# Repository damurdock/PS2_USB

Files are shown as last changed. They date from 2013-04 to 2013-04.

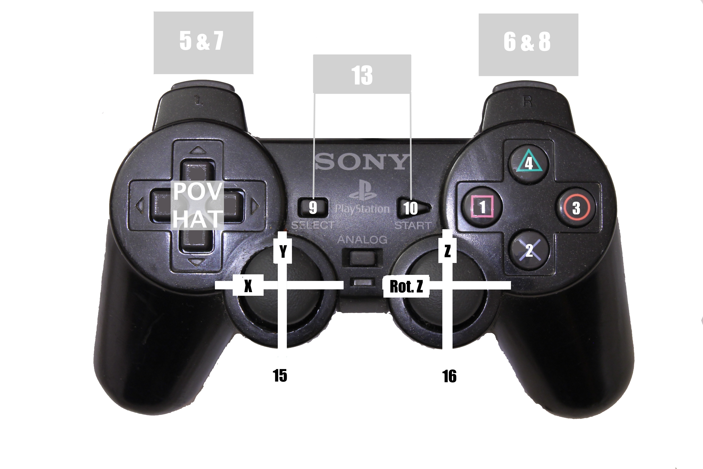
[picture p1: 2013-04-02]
Button Diagram.jpg

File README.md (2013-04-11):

##PS2-USB

###Requirements
To setup and use PS2-USB, you'll need:
  * A PJRC Teensy 2.0
  * A copy of Arduino 1.0 or higher with Teensyduino installed 
  * Either
    * Two (2) 5.6k resistors
    * Or to convert your Teensy to 3.3 volts
  * One (1) 10k resistor
  * Either some perfboard, or a PCB made from the provided files
  * Header pins or wire, depending on how you build PS2-USB
  * A PS2 Controller (non-3.3v version only tested with official Dualshock 2 controller)
  * A method of connecting your controller to the circuit
  
###Wiring
PS2-USB can be used in two configurations, 5v and 3.3v. CadSoft EAGLE board and schematics are available in the hardware directory. If you are using perfboard, a breadboard, a freehand circuit, or any other method, follow these instructions.

####5v
NOTE: The 5v version has only been tested and confirmed to work with an official Sony Dualshock 2 controller. Your results may vary.
Thanks to Bill Porter and Curious Inventor for their work, diagrams, and instructions.

Controller ---------------> Teensy  
Pin 1 ----------> Pin B3  
&nbsp;&nbsp;&nbsp;&nbsp;&nbsp;&nbsp;&nbsp;&nbsp;&nbsp;&nbsp;|-----(10k resistor)--> VCC  
Pin 2 ---------> Pin B1  
Pin 3 NC  
Pin 4 ---------> GND  
Pin 5 ---------> VCC  
Pin 6 --(5.6k resistor)--> Pin B2  
Pin 7 --(5.6k resistor)--> Pin B0  
Pin 8 NC  
Pin 9 NC  

####3.3v
NOTE: This requires that you [convert your Teensy to 3.3 volts](http://www.pjrc.com/teensy/3volt.html) or [run it from an external 3.3 volt supply] (http://www.pjrc.com/teensy/external_power.html).
Thanks to Bill Porter and Curious Inventor for their work, diagrams, and instructions.

Controller --------------> Teensy  
Pin 1 ----------> Pin B3  
&nbsp;&nbsp;&nbsp;&nbsp;&nbsp;&nbsp;&nbsp;&nbsp;&nbsp;&nbsp;|-----(10k resistor)--> VCC  
Pin 2 ---------> Pin B1  
Pin 3 NC    
Pin 4 ---------> GND  
Pin 5 ---------> VCC  
Pin 6 ---------> Pin B2  
Pin 7 ---------> Pin B0  
Pin 8 NC  
Pin 9 NC  

###Software
The PS2-USB software is written in Teensyduino, which means that you need to have a a current (1.0 or above) version of the Arduino software installed, as well as the PJRC Teensyduino software.

To setup the software, simply open PS2_USB.ino in Arduino, select "Teensy 2.0" as the board type, "Keyboard \+ Mouse \+ Joystick" as the USB type, and "16 MHz" as the CPU speed (8 MHz if running on 3.3 volts). Then, hit verify, and wait for the Teensy Loader to open. When Teensy Loader is open, make sure your Teensy is connected and hit the reset button on the Teensy. After the code is loaded, you're good to go!

###Playstation 3
PS2-USB is now fully compatible with the Playstation 3! All buttons and axes will work by default. In order to use the "PS button", install the Teensyduino PS Button Mod located [here](https://github.com/damurdock/Teensyduino-PS-Button-Mod). Pressing Start and Select at the same time sends the PS button.

###Usage
PS2-USB shouldn't require any extra work once the hardware is built and the software loaded. There are a few things you should know, however. When PS2-USB is connected, the Teensy's LED will indicate its' status. If the light is flashing, either no controller is connected, or PS2X cannot talk to the controller. Try the instructions on [this page](http://www.billporter.info/arduino-playstation-2-controller-library-troubleshooting-guide/), or try using the 3.3 volt version. Once your controller is working, you may want to look at the Button Diagram.jpg file to see how the buttons are numbered (This diagram is based on a diagram available on the PJRC website. Photo taken by Duncan Murdock, Playstation is a registered trademark of Sony).

###Credits
PS2-USB relies upon the [PS2X library by Bill Porter] (http://www.billporter.info/playstation-2-controller-arduino-library-v1-0/) and the [PJRC Teensyduino joystick library] (http://www.pjrc.com/teensy/td_joystick.html). I would also like to thank Curious Inventor for their PS2 controller interface guide, and Bill Porter for his troubleshooting guide. 

PS2-USB's hardware uses parts from the Sparkfun Eagle Library, as well a modified part for the Teensy 2.0 created by Mark Gross. The modified version, details, and license are in the hardware directory.

PS2-USB is written and maintained by Duncan Murdock. PS2-USB and all related works by Duncan Murdock are licensed under the MIT License unless otherwise noted. A copy of the MIT License is provided in the accompanying LICENSE file. If the LICENSE file is not included or is damaged in some way, a copy can be viewed at http://www.opensource.org/licenses/mit-license.php.

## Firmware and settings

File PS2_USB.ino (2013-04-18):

/******************************************************************************
 *                                 PS2-USB                                     *
 *=============================================================================*
 *                             By: Duncan Murdock                              *
 *                             Date: 1/20/2012                                 *
 *                             Version: 4                                      *
 *+++++++++++++++++++++++++++++++++++++++++++++++++++++++++++++++++++++++++++++*
 *  Uses a Teensy 2.0 in Joystick mode to convert a PS2 controller to USB.     *
 * Based on the PJRC Joystick example and Bill Porter's excellent PS2X library *
 * Hardware and software are currently TESTED. Licensed under the MIT license  *
 * , a copy of which is located in the included LICENSE file.                  *
 *                                 Enjoy!                                      *
 *-----------------------------------------------------------------------------*
 *                       https://github.com/damurdock                          *
 ******************************************************************************/

#include <PS2X_lib.h>
PS2X controller;
int error = 0;
byte type = 0;
boolean config = false;

void setup(){
  error = controller.config_gamepad(0,1,2,3, false, false); // setup controller, config_gamepad(clock, command, attention, data, Pressures?, Rumble?); rumble and pressures currently unsupported
    //Guitar Hero controllers should work now. I don't have one to test though.
}

void loop(){
  if(error == 1){ // flash led if there's an error
    digitalWrite(11,HIGH); 
    delay(500);
    digitalWrite(11,LOW); 
    delay(500);
    error = controller.config_gamepad(0,1,2,3, false, false); // Try to setup the controller again
  }
  else if (!config) { // turn on the LED and get controller type if all's well
    digitalWrite(11,HIGH); 
    type = controller.readType();
    config = true;
  }
  controller.read_gamepad(); //read the controller
  // testing out sending the usb packet spontaneously, should reduce lag a bit
  if(type !=2){ 
    Joystick.button(1, controller.Button(PSB_PINK));
    Joystick.button(2, controller.Button(PSB_BLUE));
    Joystick.button(3, controller.Button(PSB_RED));
    Joystick.button(4, controller.Button(PSB_GREEN));
    Joystick.button(5, controller.Button(PSB_L1));
    Joystick.button(6, controller.Button(PSB_R1));
    Joystick.button(7, controller.Button(PSB_L2));
    Joystick.button(8, controller.Button(PSB_R2));
    Joystick.button(11, controller.Button(PSB_L3));
    Joystick.button(12, controller.Button(PSB_R3));
    
    // working on PS3 compatibility, start && select will work as the PS button
    if(controller.Button(PSB_SELECT) && controller.Button(PSB_START)){
      Joystick.button(13, 1);
      Joystick.button(9, 0);
      Joystick.button(10, 0);
    }
    
    else if(controller.Button(PSB_SELECT) &! controller.Button(PSB_START)){
      Joystick.button(9, 1);
    }
    
    else if(!controller.Button(PSB_SELECT) & controller.Button(PSB_START)) {
      Joystick.button(10, 1);
    }
    else {
      Joystick.button(13, 0);
      Joystick.button(9, 0);
      Joystick.button(10, 0);
    }
    
    // treat the dpad like a POV hat
    if(controller.Button(PSB_PAD_LEFT) && !controller.Button(PSB_PAD_UP) && !controller.Button(PSB_PAD_DOWN)){
      Joystick.hat(270);
    }
    else if(controller.Button(PSB_PAD_RIGHT) && !controller.Button(PSB_PAD_UP) && !controller.Button(PSB_PAD_DOWN)){
      Joystick.hat(90);
    }
    else if(controller.Button(PSB_PAD_UP) && !controller.Button(PSB_PAD_RIGHT) && !controller.Button(PSB_PAD_LEFT)){
      Joystick.hat(0);
    }
    else if(controller.Button(PSB_PAD_DOWN) && !controller.Button(PSB_PAD_RIGHT) && !controller.Button(PSB_PAD_LEFT)){
      Joystick.hat(180);
    }
    else if(controller.Button(PSB_PAD_LEFT) && controller.Button(PSB_PAD_UP)){
      Joystick.hat(315);
    }
    else if(controller.Button(PSB_PAD_LEFT) && controller.Button(PSB_PAD_DOWN)){
      Joystick.hat(225);
    }
    else if(controller.Button(PSB_PAD_RIGHT) && controller.Button(PSB_PAD_UP)){
      Joystick.hat(45);
    }
    else if(controller.Button(PSB_PAD_RIGHT) && controller.Button(PSB_PAD_DOWN)){
      Joystick.hat(135);
    }
    else {
      Joystick.hat(-1);
    }
    
    Joystick.X(map(controller.Analog(PSS_LX),0,255,0,1023)); // updated to use map(), which is designed for this
    Joystick.Y(map(controller.Analog(PSS_LY),0,255,1023,0)); // these axes are inversed for some reason
    Joystick.Z(map(controller.Analog(PSS_RX),0,255,0,1023));
    Joystick.Zrotate(map(controller.Analog(PSS_RY),0,255,1023,0));
  }
  else if(type == 2){ // guitar hero
    // mapping thanks to http://strategywiki.org/wiki/Guitar_Hero_II/Controls
    Joystick.button(8, controller.Button(GREEN_FRET));
    Joystick.button(3, controller.Button(RED_FRET));
    Joystick.button(4, controller.Button(YELLOW_FRET));
    Joystick.button(2, controller.Button(BLUE_FRET));
    Joystick.button(1, controller.Button(ORANGE_FRET));
    Joystick.button(9, controller.Button(STAR_POWER));
        
    if(controller.Button(UP_STRUM) || controller.Button(DOWN_STRUM)){ // if you strum at all, this button goes true.
      Joystick.hat(0);
    }
    else {
      Joystick.hat(-1);
    }
    
    // working on PS3 compatibility, start && select will work as the PS button (hopefully)
    if(controller.Button(PSB_SELECT) && controller.Button(PSB_START)){
      Joystick.button(14, 1);
    }
    
    else if(controller.Button(PSB_SELECT) &! controller.Button(PSB_START)){
      Joystick.button(7, 1);
    }
    
    else if(!controller.Button(PSB_SELECT) & controller.Button(PSB_START)) {
      Joystick.button(8, 1);
    }
    
    Joystick.Y(map(controller.Analog(WHAMMY_BAR),0,255,0,1023));
    Joystick.send_now();
  }
}

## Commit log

2012-06-06 First commit!
    Hardware and software are currently UNTESTED. Should work fine, but I
    don't have my Teensy yet. I'm not responsible if something breaks
    though.
    TODO:
    Readme file
    Github site
    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
    [PS2-USB.fzz]
2012-06-10 It works!
    Hardware and software both work with an official Sony PS2 controller. I
    added a bit of error-handling, now the teensy will flash it's onboard
    LED and attempt to setup the controller again. This brings it a bit
    closer to hot-plug capable, but true hot-plugability will likely need
    changes in the library.
    Convert hardware to EAGLE
    README, LICENSE, etc.
    Better Hot-Plug Support
    Github Site
    Guitar Hero Support
    Force Feedback/Rumble
    P.S.: I have no clue how to implement rumble through Teensyduino. I'm
    digging through other projects now, but if you've done this before, or
    can offer any tips or help please shoot me an email. Or a pull request
    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
    [PS2_USB.ino]
2012-06-12 Small change
    Deleted a bit of extraneous code that fixed a compile error on my end
    (which ended up fixing itself) but had no real function. Hardware and
    software both work well in real world testing. There might be a bit of
    lag in the button handling, but I'm not sure. I haven't had much
    opportunity to test the analog sticks, but they seem to work ok.
    [PS2_USB.ino]
2012-06-13 Small Board Revision
    [PS2-USB.fzz]
2013-04-02 BIG CHANGES!
    Big changes and two revisions here! First, guitar controllers should
    work! I don't have one to test, but the code is there. You will have to
    re-map the controller though. I'll try to map them both. Second,
    PS2-USB is PS3 compatible(ish)! All the buttons and axes work,
    including the D-Pad (which was changed to a POV hat for compatibility)!
    Currently, the PS button is not supported, but I'm working on that now.
    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
    [PS2-USB.fzz, PS2USB.brd, PS2USB.sch]
2013-04-11 PS3 Working!
    Teensyduino now works with the PS3 (instructions in the readme). This
    will be the last revision for a while, the code is pretty much final at
    this point.
2013-04-18 More changes!
    So, I was really wrong when I said that would be the last commit for a
    while. I've made a few changes which should improve responsiveness. I
    also redid the guitar controller mapping to match how GH maps the
    dualshock to the guitar.
    [PS2_USB.ino]
